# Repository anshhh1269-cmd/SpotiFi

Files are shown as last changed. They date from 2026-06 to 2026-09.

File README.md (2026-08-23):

# SpotiFi

An ESP32-powered desktop toy that interfaces with the Spotify Web API to display live track metadata, custom retro animations, and interactive player visualizations on an ILI9341 TFT display. This display is a hardware-software hybrid where physical screens meet APIs and WiFi connections.

# The Reason

Now, why did I choose this project over all amazing starter projects?
First obvi it looks more on the easier side compared to the rest of them and my main objective was to learn Fusion360 through it to master my skillset in CAD and 3D Printing. Second this display looked like something I could actually use or someone else could if they like keeping their surroundings more towards the side of a cosy vibe. 

# The Functionality

Firstly, hardware:
SpotiFi contains a TFT display, an ESP32, and five switches..each of the switches have a functionality; 

First Button: Forward
Second Button: Pause/Play
Third button: Backwards
Fourth button: 3 modes ( an inspiration from my sister); one of the modes is where the screen would show the cover image of the song/album and a character on the side which moves/vibes, others include a live oscilloscope and a character-only mode.

The ESP32 device will connect to the local Wi-Fi network of your home and use the OAuth 2.0 authentication to create a secure connection between the ESP32 and the Spotify Web API. It will send a series of background HTTP requests to the API at regular intervals in order to retrieve a real-time JSON payload containing track information such as track title, artist name, and playback state.

Then, the processed data will be transferred to the ILI9341 display controller in order to update the text and graphics on the screen. When you press any of the physical buttons, a reverse command will be sent to the Spotify server through the corresponding GPIO input.

# 3D Model Sponsorship 

# JUSTWAY Services

JUSTWAY is an online manufacturing platform that provides high-quality custom manufacturing services, including CNC machining, 3D printing, sheet metal fabrication, injection molding, PCB assembly, and 
rapid prototyping. Their platform allows engineers, makers, and students to upload CAD models, receive instant quotations, and manufacture custom parts efficiently.

# Ordering Process

**The Uploading Process**: There is an easy CAD upload for 3D Printing which gives us a 3D View right there in Justway's 
website; it consists of many options for 3D Printing along with matte paint and sanding.



**The Approval**: A good thing from Justway is that the 3D Printing job is looked at before it has been ordered for any
problems; and when it's approved, the user can then only order the job. 



**The Shipping**: Justway has multiple pages for production, delivery, and completed pages for better user interaction
and better control.

# The Unboxing

**The Packaging**: The product was safely packed under many layers when received. It was packed under a box from JustWay, secured with bubble wrap and cardboard. 





**The Product Images**: 











IMG_5625 (1)

## Dimensions and Precisions

One of the most important aspects of this project was achieving accurate dimensions, as every component inside the enclosure had to fit precisely without requiring major modifications. The USB opening was 
printed with excellent accuracy, allowing the USB connector to align perfectly with the ESP32's port. This ensured that the device could be charged and programmed easily while maintaining a clean exterior. The back cover also fit the main body precisely. The mating surfaces aligned well, creating a secure and professional fit without noticeable gaps or excessive force during assembly.

Another critical feature was the cutouts for the mechanical keyboard switches. These openings were manufactured with high dimensional accuracy, allowing the switches to fit properly and remain 
firmly seated in the enclosure. 





## End Application

Spotifi is a portable ESP32-based smart music player designed as a personal engineering project that combines embedded systems, electronics, and mechanical design. The custom enclosure securely houses
the ESP32, TFT display, battery, mechanical keyboard switches, and other electronic components, making it a functional and portable device.

## JUSTWAY Advantages

Throughout this project, JUSTWAY provided a smooth and user-friendly manufacturing experience. Uploading the CAD files and placing the order was straightforward, making the process accessible even 
for a student working on a personal engineering project.

Communication with the JUSTWAY team was also professional and responsive. Whenever I had questions regarding my order, they replied promptly and were willing to help resolve any issues.

Overall, JUSTWAY offers an excellent combination of manufacturing quality, ease of ordering, responsive customer support, and reliable precision, making it a great choice for engineers, students, 
and makers developing custom prototypes or functional products.

# The 3D Model











**Public Link: https://a360.co/4dSKmTr**

# The Wiring

Schematic_SpotiFi_2026-06-15

EasyEDA Link: https://easyeda.com/editor#project_id=699845724ab2404091f892d3d4bc927d

## 📊 Bill of Materials (BOM)

| Item | Quantity | Use | Cost (THB) + Shipping | Link |
| :--- | :---: | :--- | :---: | :--- |
| **Stranded Silicone Wires** | 4-5 meters | wire components together by solder | 630 | https://shopee.co.th/1-5-10-Meter-Number-6-30AWG-0.08mm-UL-Stranded-Silicone-Flexible-Cable-600V-200%C2%B0C-i.1096643478.27219985090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 |
| **ESP-32 30-pin** | 1 | microcontroller | 230 | https://shopee.co.th/ESP32-ESP-32-DOIT-DEVKIT-V1-Layout-Development-Board-30-Pin-i.128765755.4216421644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 |
| **LCD TFT Screen** | 2 | The screen is used to display the output from Spotify API | 300 | https://shopee.co.th/%E0%B8%82%E0%B8%AD-LCD-TFT-1.8%E0%B8%99%E0%B8%B4%E0%B9%89%E0%B8%A5-RGB-128x160px-SPI-SNP-00086-i.1272136510.26451852926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 |
| **Tactical Switches** | 5 | Switches usedto control the output executed | 63 | https://shopee.co.th/Outemu-Switch-Red-Switch-Blue-Switch-%E0%B8%9B%E0%B8%B5%E0%B9%88%E0%B8%A1%E0%B8%AA%E0%B8%A7%E0%B8%B4%E0%B8%95%E0%B8%8A%E0%B9%8C-Mechanical-Keybo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 |
| **Soldering iron** | 1 | needed to solder parts together | 179 | https://shopee.co.th/%E0%B8%8A%E0%B8%B5%E0%B8%AB%E0%B8%B5%E0%B8%A3%E0%B9%82%E0%B8%9F%E0%B8%9F%E0%B9%8A%E0%B8%B2-15-%E0%B8%8A%E0%B8%B4%E0%B8%A3-%E0%B8%A1%E0%B8%A3%E0%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 |
| **Hot glue gun sticks** | 1 pack | needed for my hot glue gun | 109 | https://shopee.co.th/50-%E0%B8%8A%E0%B8%B4%E0%B9%83%E0%B8%A3-7-%E0%B8%A1%E0%B8%B4%E0%B8%A5%E0%B8%A5%E0%B8%B4%E0%B9%80%E0%B8%A1%E0%B8%95%E0%B8%A3-100-%E0%B8%A1%E0%B8%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 |
| **Solder Wire** | 1 | needed for the soldering iron | 630 | https://shopee.co.th/63-37-Tin-Rosin-Core-20g-0.8-%E0%B8%A1%E0%B8%A1.%E0%B8%A5%E0%B8%A7%E0%B8%94%E0%B8%9A%E0%B8%B1%E0%B8%94%E0%B8%81%E0%B8%A3%E0%B8%B5%E0%B8%9E%E0%B8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 |
| **M2 Screws** | 1 | needed to screw ESP32 and TFT Screen to the 3D Printed SpotiFi | 167 | https://shopee.co.th/%E0%B8%8A%E0%B8%B5%E0%B8%94%E0%B9%80%E0%B8%AA%E0%B8%B2%E0%B8%97%E0%B8%AD%E0%B8%81%E0%B9%80%E0%B8%AB%E0%B8%A5%E0%B8%B7%E0%B8%AD%E0%B8%81-%E0%B9%8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 |

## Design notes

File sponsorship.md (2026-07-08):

# JUSTWAY Services

JUSTWAY is an online manufacturing platform that provides high-quality custom manufacturing services, including CNC machining, 3D printing, sheet metal fabrication, injection molding, PCB assembly, and 
rapid prototyping. Their platform allows engineers, makers, and students to upload CAD models, receive instant quotations, and manufacture custom parts efficiently.

# SpotiFi Background

Spotifi is a portable Spotify-inspired music player that I designed and built from scratch as a personal engineering project. The device integrates an ESP32, TFT display, custom electronics, and a 3D-printed
enclosure. Since every internal component had to fit precisely, I designed the enclosure entirely in CAD and required accurate custom 3D printing. Moreover, it consists of five switches; those are for volume/back/forward,
the fifth switch is for three modes which are character display, song display and oscilloscope display.

# Ordering Process

**The Uploading Process**: There is an easy CAD upload for 3D Printing which gives us a 3D View right there in Justway's 
website; it consists of many options for 3D Printing along with matte paint and sanding.



**The Approval**: A good thing from Justway is that the 3D Printing job is looked at before it has been ordered for any
problems; and when it's approved, the user can then only order the job. 



**The Shipping**: Justway has multiple pages for production, delivery, and completed pages for better user interaction
and better control.

# The Unboxing

**The Packaging**: The product was safely packed under many layers when received. It was packed under a box from JustWay, secured with bubble wrap and cardboard. 





**The Product Images**: 











IMG_5625 (1)

## Dimensions and Precisions

One of the most important aspects of this project was achieving accurate dimensions, as every component inside the enclosure had to fit precisely without requiring major modifications. The USB opening was 
printed with excellent accuracy, allowing the USB connector to align perfectly with the ESP32's port. This ensured that the device could be charged and programmed easily while maintaining a clean exterior. The back cover also fit the main body precisely. The mating surfaces aligned well, creating a secure and professional fit without noticeable gaps or excessive force during assembly.

Another critical feature was the cutouts for the mechanical keyboard switches. These openings were manufactured with high dimensional accuracy, allowing the switches to fit properly and remain 
firmly seated in the enclosure. 





## End Application

Spotifi is a portable ESP32-based smart music player designed as a personal engineering project that combines embedded systems, electronics, and mechanical design. The custom enclosure securely houses
the ESP32, TFT display, battery, mechanical keyboard switches, and other electronic components, making it a functional and portable device.

## JUSTWAY Advantages

Throughout this project, JUSTWAY provided a smooth and user-friendly manufacturing experience. Uploading the CAD files and placing the order was straightforward, making the process accessible even 
for a student working on a personal engineering project.

Communication with the JUSTWAY team was also professional and responsive. Whenever I had questions regarding my order, they replied promptly and were willing to help resolve any issues.

Overall, JUSTWAY offers an excellent combination of manufacturing quality, ease of ordering, responsive customer support, and reliable precision, making it a great choice for engineers, students, 
and makers developing custom prototypes or functional products.

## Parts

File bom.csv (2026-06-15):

Item | Quantity | Use | Cost(thb)+shipping | Link
Stranded Silicone Wires | 4-5 meters | wire components together by solder | 630 | https://shopee.co.th/1-5-10-Meter-Number-6-30AWG-0.08mm-UL-Stranded-Silicone-Flexible-Cable-600V-200%C2%B0C-i.1096643478.27219985090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
ESP-32 30-pin | 1 | microcontroller | 230 | https://shopee.co.th/ESP32-ESP-32-DOIT-DEVKIT-V1-Layout-Development-Board-30-Pin-i.128765755.4216421644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
LCD TFT Screen | 2 | The screen is used to display the output from Spotify API | 300 | https://shopee.co.th/%E0%B8%88%E0%B8%AD-LCD-TFT-1.8%E0%B8%99%E0%B8%B4%E0%B9%89%E0%B8%A7-RGB-128x160px-SPI-SNP-00086-i.1272136510.26451852926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
Tactical Switches | 5 | Switches usedto control the output executed | 63 | https://shopee.co.th/Outemu-Switch-Red-Switch-Blue-Switch-%E0%B8%9B%E0%B8%B8%E0%B9%88%E0%B8%A1%E0%B8%AA%E0%B8%A7%E0%B8%B4%E0%B8%95%E0%B8%8A%E0%B9%8C-Mechanica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
Soldering iron | 1 | needed to solder parts together | 179 | https://shopee.co.th/%E0%B8%8A%E0%B8%B8%E0%B8%94%E0%B8%AB%E0%B8%B1%E0%B8%A7%E0%B9%81%E0%B8%A3%E0%B9%89%E0%B8%87%E0%B9%84%E0%B8%9F%E0%B8%9F%E0%B9%89%E0%B8%B2-1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
Hot glue gun sticks | 1 pack | needed for my hot glue gun | 109 | https://shopee.co.th/50-%E0%B8%8A%E0%B8%B4%E0%B9%89%E0%B8%99-7-%E0%B8%A1%E0%B8%B4%E0%B8%A5%E0%B8%A5%E0%B8%B4%E0%B9%80%E0%B8%A1%E0%B8%95%E0%B8%A3-100-%E0%B8%A1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
Solder Wire | 1 | needed for the soldering iron | 630 | https://shopee.co.th/63-37-Tin-Rosin-Core-20g-0.8-%E0%B8%A1%E0%B8%A1.%E0%B8%A5%E0%B8%A7%E0%B8%94%E0%B8%9A%E0%B8%B1%E0%B8%94%E0%B8%81%E0%B8%A3%E0%B8%B5%E0%B8%9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
M2 Screws | 1 | needed to screw ESP32 and TFT Screen to the 3D Printed SpotiFi | 167 | https://shopee.co.th/%E0%B8%8A%E0%B8%B8%E0%B8%94%E0%B9%80%E0%B8%AA%E0%B8%B2%E0%B8%97%E0%B8%AD%E0%B8%87%E0%B9%80%E0%B8%AB%E0%B8%A5%E0%B8%B7%E0%B8%AD%E0%B8%87-%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

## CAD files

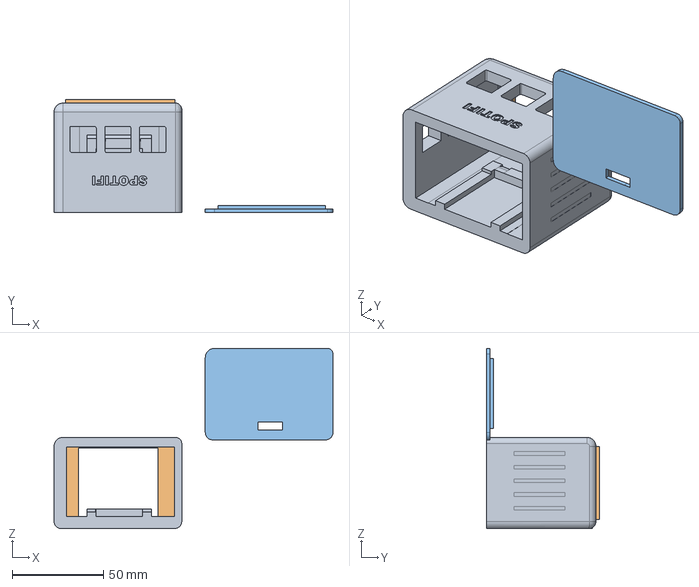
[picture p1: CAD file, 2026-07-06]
3D Model/SpotiFi (5).stp
152.8 x 62.0 x 98.7 mm

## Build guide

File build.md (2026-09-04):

# 2026-08-24: time for the three switchess

**Total time spent: 1.2 hours**

aight so now the clay thing from last time was def not working cause it was kinda conducting but it was slipping out whenever put in a cramped position so i thought and thought...andd 
HOTT GLUE came in my mind why not hot glue the female header pins directly to the base of the switches it wont move that easily even when positioned a lot or 
its position is changed many times

so i hot glued three switches meaning six header wires did take some time cause hot glue is kinda messy but then it was stuck perfectly..moving onto the problem of connecting the three 
gnd wires to one GND pin on the esp32..now solder wasnt working out for me so i basically had to get **creative** again and again..so i had an idea of those three gnd wires im gonna 
scrape the end and expose the copper

then the expose copper can be layered onto the pin of the esp32 but one thing was it could come off again..and then on my table those circle stickers were kept which had glue on the other side;
so i took out one cut it into a small piece and then put the glue tape on both the sides of the gnd pin of the esp and then just stick it..and then i used those tightening wires and then 
it kinda worked dont knowif it will come out but temporary fix :)

thats it for tdy :)

WhatsApp Image 2026-09-04 at 23 38 32

WhatsApp Image 2026-09-04 at 23 38 32 (1)

# 2026-08-22: the wiring

**Total time spent: 0.67 hours**

okay so i connected the wires from the screen header pins to the esp32 along with one switch with clay idk how to do it man im confused let’s see
thats it for tdy :)

# 2026-08-21: got the pcb

**Total time spent: 1.3 hours**

okay i got the pcb and header pins; started soldering the header pins on the pcb..but idk why when i connected th wires the screen aint turning on
idk gotta see wat happened..anw thats it for tdy :); **lapse link: https://lapse.hackclub.com/timelapse/vXb8___Yu2VA**



# 2026-08-13: designed PCB

**Total time spent: 1.2 hours**

so yea i tried everything to connect the wires with soldering, black tape and nothing is sticking honestly and idk why..
so ill be ordering a pcb from jlcpcb and i have designed it..dont have a lapse for it cause forgot but took me a little more than an hour..i added a 10 header pin and a eight header pin for the screen and the switches so its easy to connect and stuff so lets see if this will work too..
thats it for tdy :)





# 2026-08-08: doing the switches

**Total time spent: 1.5 hours**

so tdy was trial and error; i tried soldering the wires onto the siwtches but it aint sticking man idk why i think i gotta learn still
however im trying to do it with tape and honestly no progress yet but this lapse was me trying it :(

**lapse link: https://lapse.hackclub.com/timelapse/6K3eVTo8P4Ux**



# 2026-08-05: assembly time

**Total time spent: 1.25 hours**

so im using the female-to-female wires now; first i started with looking on how the screen would attach to the 3D printed body; used black tape and did again and again cause my 3d print wasnt that perfect :(
and then after that started to use the female-to-female wires however the solder lump was still on the pins so it wasnt fitting; rmeoved the solder iron again and heaed it up to remove those tiny lumps;
after that i connected everything carefully but however there is a slight problem; the usb cable which connects to the esp32 port is to big to fit through my back case hole; idk what to do will check and research :(

**lapse link: https://lapse.hackclub.com/timelapse/SK1I42jsH6JG**



# 2026-08-05: removing the soldered wiress

**Total time spent: 0.5 hours**

okay so picking up where i left on soldering; the soldering wasnt working well on the pins so im gonna be using 10cm F-F wires..

**lapse link: https://lapse.hackclub.com/timelapse/jAO-Ja1L0aNU**



# 2026-08-02: soldering part one

**Total time spent: 2 hours**

soo end result i hate soldering now and i have crashed out..i have offically ordered smaller female-female wires cause this soldering thing will take time to master :(
kinda bad technique the wires did stick first but came out when i tried some other pinn near it..will learn but not now :(

**lapse link: https://lapse.hackclub.com/timelapse/k3ah_FwGRwMV**



# 2026-07-28: finished the initial wiring

**Total time spent: 0.67 hours**

so i got the female=to-female connecting wires and started to put them into use..first thing was to connect the screen to the esp32 which seemed hard at first cause i havent done any hardware yet..but this seemed so easy
i didnt even have to use chat for this just used the knowledge i gained before while doing the design and just translated into real life..
added a time lapse video too..seems very bad ngl but yea it is what it is
thats it for rn..and also i added one switch to it..cant add five switches using the wires due to GND prob..so im just gonna use this switch and try out the coding like character dancing or spotify api connecting.

**lapse link: https://lapse.hackclub.com/timelapse/BUhdfQgGlOS-**



# 2026-07-27: STARTED the build :)

**Total time spent: 1.2 hours**

okay so my first build..pretty excited
so the first thing was to find the cheapest switches, esp32, and the tft screen which was quite easy..also started to find soldering kit along with solder wire, and a data USB cable cause i dont have one which works..
the things came and i have just started out to test the esp32 nothing else no code yet; and a thing came to my mind which was supposed to come way before; ill use the female-to-female connectors instead of solder just for testing so i dont have to solder and rmeove solder again and again...already ordered those
so this devlog covered the ordering time, along with the esp32 and i also got the 3d print through a sponsorship from justway!







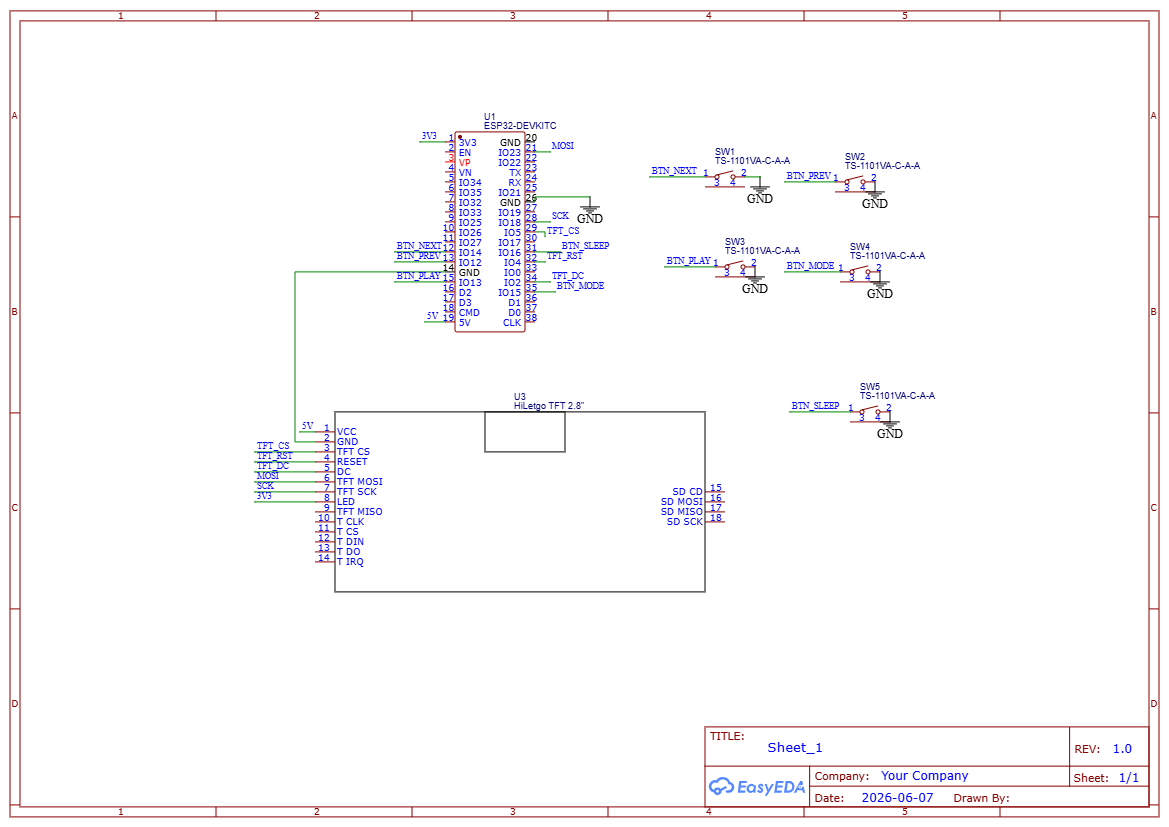
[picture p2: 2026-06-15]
Wiring/Schemantic.png

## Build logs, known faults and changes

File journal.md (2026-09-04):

# 2026-06-15: wiring and keyboard buttons

**Total time spent: 2.50 hours**

so basiclly my proj got returned today..main thing was the wiring was so messy and not exactly an easy readable file..so what I did was use net label in easyEDA which i've never heard off...its basically like u can write the pin u want to connect to each end of the wire without making these long green ones

however i did crashout kinda today..so i did one wire like this and i had to check if it was rlly connected..AI told me to click one of the label and the other label should highlight automatically, however it didnt...and tried again and still no outcome

asked for other option where i ahd to check in the nets tab in easyEDA and when i cliked "5V" both of them had highlighted so got a bit excited

did for all and it kinda looks clean and then moving onto the keyboard..so basically i had got the keyboard buttons from GRABCAD but i forgot to even try it in the holes made..did it today and got it on perfectly; took some time as i had to figure out the correct angle and everything :(

moving onto finding the 3D quote in 3D Legion by hackclub :)





# 2026-06-07: code completed

**Total time spent: 1.1 hours**

yea so made the code for the esp32...first listed out the libraries needed then explained and executed each and every possibilities for each mode...made it so that the eso32 uses my home wifi by inputting the ssid and its password

so hwo this works is that when the ESP32 gets fired up it connects to my WiFi and then connects through the Spotify's API provided by me through the user code and secret code, then it would request the API to send cover album, name, title and sound track to track the oscilloscope..

the character dancing on one of the modes would be like a pre-decided one which would be in the code made by hexadecimal and binary codes.

couldnt be seen in hacaktime due to some error i think and also i tried time lapse and the whole file just got deleted

i took like 1.5hrs but ill write it as one hr :)



# 2026-06-07: recheck everything

**Total time spent: 4.1 hours**

so i had to check everything today...gguess what?

the TFT screen which i used is way bigger in real life and now the screen might not even make it..however i tried not to waste time with it but i did go through the timeline to recheck again

found everything online today and made the bom.csv too (took 30 mins) now working on the code and also looked up a 3D Printer vendor today and made a quote so yeaa...

AND also worked on the wiring in easyeda which took time but i think i did it well...i might do like a simulation of these all parts and recheck everything

ANDDD remember the shadowing effect on the tft screen on the back side..so today i went back to the timeline and made the initial rectangle smaller and finally i cud see the screw mounts on the back side and that helped a lott...but the thing is since the real size cud be bigger or smaller than this i thought to add screws on the mounts but that didn't work out since the circles weren't allowing me to sketch on the components idk why..

so then i asked people and AI for some advice and they said that maybe using glu tack would be a better resort and i thought that would be good too, instead of drilling more holes and cylinders on the 3D structure :)

thats it :)





# 2026-06-05: made the cover more proper

**Total time spent: 2.0 hours**

NOWW THE BAD THING HAPPENED!

now before in one of the devlogs i made the back cover but i forgot to actually check it by putting/moving it on the back side of the case

well i did it today and guess what? the usb port wasnt in the hole like only 50% of it was in there...so again i had to take some dimensions and make the hole more bigger on the case, and then after some trial and error, it had finally fit and i had a sigh of relief honestly.

and honestly i way i could have gone was to just make the hole more bigger but then that would defeat its purpose to just show the usb port and dust could also form so i took all dimensions again and then did the whole thing again..





# 2026-06-04: added some kinda cool things

**Total time spent: 2.67 hours**

so first after some time off from my exams i started to work on this project...

someone gave me an advice and told me to add like a continuous LED screen which showed the song playing on each side...however later after one hr of tryin i found that i couldn't do it cause the filet and some other locked things weren't letting me change the dimensions :(

and then just to make timepass i added some cool things like SPOTFI on top and added some grip grooves on each side idk just like that and also fixed sum things by going back in the timeline

now these grooves are obvi for cool deisgns and also to decrease and shed some weight out of it to make it more portable.





# 2026-05-25: big day today

**Total time spent: 4.3 hours**

sooo basically i got the case working after sooo long...first i was making the case on the back side but it wasn't workin so i just got each and every dimensions and made the case seperately and its fittinggg :)

so firstly, didnt know how to make a back case..had some help..soo first i did like took all the dimensions of the outer rectangle, inner and inner with a gap of 2mm and more important the usb hole so that the port can just slide in and be open to any connections to the ESP 32. however, idk why when i did that the case wasn't coming out and i couldn't obvi make a 3D print with both of em being together;

so then i had an idea to just make it in the universe take all the dimensions again exactly like how far is this line from the outer and everything which took some time to memorize and execute but it did happen eventually;

also matched the 5mm filets and i think it would be good





# 2026-05-24: added the ESP32...and made it's case

**Total time spent: 3.5 hours**

soo basically i have figured out on how to attach the ESP32 to the bottom of the case abd it actually worked..kinda

and also made a case for it and also added two rectangles on top of it to secure the ESP..

now see in this pic you guys cud see the shadow thingy i was talking for the screen and how its corners arent even visible i think its just submerged in the corners gotta make it small by going through the timeline..also these rectangles on the side and on the top would prevent left-right motion and for the upward and downward i thought to create some other rectangle but i think making a back cover would solve all problems and would also make this project more smoother and like it would have a closing gap.

next im gonna make a back cover and then on to the keyboard stuff...



# 2026-05-23: added ths screen and working on ESP32

**Total time spent: 3.5 hours**

so basically i added the screen now and it actually maybe looks like what im hoping for :)...so basically the screen is coming out, which it should do but also when im trying to use the "m" function in fusion by selecting points of ESP and that inward part it just doesnt seem to be working..idk will look into it :(

more things which i did obvi first extruded from the first part to make like a box and an extra thing was to filet the edges so it kinda looks cool..did it like 5mm hopefully thats enough;

moreover, idk why but the red part of the screen behind it is coming as a shadow like its having those color effects idk why may look to fix it a bit later i think.

adding the esp32 and hiding its pins so its easy to move was another thing done in this part

but that's it for tdy; next thing would be placing the esp32 and creating its borders so it doesn't move left and right.



# 2026-05-21: the start of a hardware journey :)

**Total time spent: 2 hours**

soo basically i have got the parts needed for this project, the screen, keyboard and the ESP32 from GRABCAD community..and i have started to make the base

thats it :) annddd im using fusion for the first time :)

so for this part what i have done is like create an outlier rectangle for the screen and then extrude so that the screen is the only one shown and not the red parts. bad thing was i took soe extra time to figure out everything like extrude/dimensions and everything :(



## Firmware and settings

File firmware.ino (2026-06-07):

#include <Arduino.h>
#include <ArduinoJson.h>
#include <Adafruit_GFX.h>
#include <Adafruit_ST7735.h>
#include <WiFi.h>
#include <HTTPClient.h>
#include <WiFiClientSecure.h>
#include <JPEGDecoder.h>
#include <SpotifyEsp32.h>
#include <SPI.h>

// ============================================================================
// 1. HARDWARE PIN CONFIGURATIONS
// ============================================================================
#define BTN_NEXT  14  
#define BTN_PREV  12  
#define BTN_PLAY  13  
#define BTN_MODE  15  
#define BTN_SLEEP 16  

#define TFT_CS    5
#define TFT_RST   4
#define TFT_DC    2
#define TFT_SCLK  18
#define TFT_MOSI  23


const char* SSID          = "YOUR WIFI SSID";
const char* PASSWORD      = "YOUR WIFI PASSWORD";
const char* CLIENT_ID     = "YOUR_SPOTIFY_CLIENT_ID";
const char* CLIENT_SECRET = "YOUR_SPOTIFY_CLIENT_SECRET";


const uint16_t charFrame1[] PROGMEM = {
    0x0000, 0x0000, 0x07E0, 0x07E0, 0x07E0, 0x07E0, 0x0000, 0x0000,
    0x0000, 0x07E0, 0xFFFF, 0x07E0, 0x07E0, 0xFFFF, 0x07E0, 0x0000,
    0x07E0, 0x07E0, 0x07E0, 0x07E0, 0x07E0, 0x07E0, 0x07E0, 0x07E0,
    0x07E0, 0x0000, 0x07E0, 0x07E0, 0x07E0, 0x07E0, 0x0000, 0x07E0,
    0x07E0, 0x07E0, 0x07E0, 0x07E0, 0x07E0, 0x07E0, 0x07E0, 0x07E0,
    0x0000, 0x07E0, 0x07E0, 0x07E0, 0x07E0, 0x07E0, 0x07E0, 0x0000,
    0x0000, 0x07E0, 0x0000, 0x0000, 0x0000, 0x0000, 0x07E0, 0x0000,
    0x0000, 0xF800, 0x0000, 0x0000, 0x0000, 0x0000, 0xF800, 0x0000
};

const uint16_t charFrame2[] PROGMEM = {
    0x0000, 0x0000, 0x07E0, 0x07E0, 0x07E0, 0x07E0, 0x0000, 0x0000,
    0x0000, 0x07E0, 0xFFFF, 0x07E0, 0x07E0, 0xFFFF, 0x07E0, 0x0000,
    0x07E0, 0x07E0, 0x07E0, 0x07E0, 0x07E0, 0x07E0, 0x07E0, 0x07E0,
    0x07E0, 0x07E0, 0x0000, 0x07E0, 0x07E0, 0x0000, 0x07E0, 0x07E0,
    0x07E0, 0x07E0, 0x07E0, 0x07E0, 0x07E0, 0x07E0, 0x07E0, 0x07E0,
    0x0000, 0x0000, 0x07E0, 0x07E0, 0x07E0, 0x07E0, 0x0000, 0x0000,
    0x0000, 0x0000, 0x07E0, 0x0000, 0x0000, 0x07E0, 0x0000, 0x0000,
    0x0000, 0x0000, 0xF800, 0x0000, 0x0000, 0xF800, 0x0000, 0x0000
};


enum DisplayMode { BOOT_TEXT, ALBUM_ART_CHAR, ONLY_CHAR, OSCILLOSCOPE };
DisplayMode currentMode = BOOT_TEXT; 

bool screenSleep = false;
String lastTrackname = "";
String lastArtist = "";
String lastAlbumUrl = "";
unsigned long lastAnimationTime = 0;
unsigned long lastSpotifyUpdate = 0;
int animationFrame = 0;
float wavePhase = 0;

float realLoudness = -10.0; 
float realBPM = 120.0;       

Spotify sp(CLIENT_ID, CLIENT_SECRET);
Adafruit_ST7735 tft = Adafruit_ST7735(TFT_CS, TFT_DC, TFT_MOSI, TFT_SCLK, TFT_RST);

// Forward Declarations
int checkMultiClicks(int pin);
void drawSpotifyAlbumArt(String url);
void renderJPEG(int xpos, int ypos);
void drawTrackText(String track, String artist);
void fetchLiveAudioFeatures(String trackId);

void setup() {
    Serial.begin(115200);
    
    pinMode(BTN_NEXT, INPUT_PULLUP);
    pinMode(BTN_PREV, INPUT_PULLUP);
    pinMode(BTN_PLAY, INPUT_PULLUP);
    pinMode(BTN_MODE, INPUT_PULLUP);
    pinMode(BTN_SLEEP, INPUT_PULLUP);

    tft.initR(INITR_BLACKTAB);
    tft.setRotation(1); 
    tft.fillScreen(ST77XX_BLACK);
    
    tft.setCursor(10, 20);
    tft.setTextColor(ST77XX_WHITE);
    tft.setTextSize(1);
    tft.print("Booting Connection...");

    WiFi.begin(SSID, PASSWORD);
    while (WiFi.status() != WL_CONNECTED) {
        delay(500);
        Serial.print(".");
    }
    
    tft.fillScreen(ST77XX_BLACK);
    tft.setCursor(10, 20);
    tft.print("Syncing Spotify API...");

    sp.begin();
    while (!sp.is_auth()) {
        sp.handle_client();
        delay(10);
    }
    tft.fillScreen(ST77XX_BLACK);
    currentMode = ALBUM_ART_CHAR; 
}

void loop() {
    sp.handle_client();

    
    if (digitalRead(BTN_NEXT) == LOW) { sp.skip_to_next(); delay(300); }
    if (digitalRead(BTN_PREV) == LOW) { sp.skip_to_previous(); delay(300); }
    if (digitalRead(BTN_PLAY) == LOW) { sp.start_a_users_playback(); delay(300); }
    if (digitalRead(BTN_SLEEP) == LOW) {
        screenSleep = !screenSleep;
        if (screenSleep) tft.fillScreen(ST77XX_BLACK);
        else { lastAlbumUrl = ""; lastTrackname = ""; }
        delay(350);
    }

    if (screenSleep) return; 

    int clicks = checkMultiClicks(BTN_MODE);
    if (clicks == 1) { currentMode = ALBUM_ART_CHAR; tft.fillScreen(ST77XX_BLACK); lastAlbumUrl = ""; lastTrackname = ""; }
    else if (clicks == 2) { currentMode = ONLY_CHAR; tft.fillScreen(ST77XX_BLACK); }
    else if (clicks == 3) { currentMode = OSCILLOSCOPE; tft.fillScreen(ST77XX_BLACK); }

   
    static String currentTrack = "";
    static String currentArtist = "";
    static String currentAlbumUrl = "";
    static String lastTrackId = "";
    static bool isPlaying = false;

    if (millis() - lastSpotifyUpdate > 2000) {
        lastSpotifyUpdate = millis();
        currentTrack    = sp.current_track_name();
        currentArtist   = sp.current_artist_names();
        currentAlbumUrl = sp.get_current_album_image_url(2); 
        isPlaying       = sp.is_playing();
        
        String currentTrackId = sp.current_track_id(); 
        
        if (currentTrackId != lastTrackId && !currentTrackId.isEmpty()) {
            fetchLiveAudioFeatures(currentTrackId);
            lastTrackId = currentTrackId;
        }
    }

    
    switch (currentMode) {
        
        case ALBUM_ART_CHAR:
            if (currentTrack != lastTrackname) {
                drawTrackText(currentTrack, currentArtist);
                lastTrackname = currentTrack;
                lastArtist = currentArtist;
            }
            if (currentAlbumUrl != lastAlbumUrl && !currentAlbumUrl.isEmpty()) {
                tft.fillRect(10, 32, 64, 64, ST77XX_BLACK); 
                drawSpotifyAlbumArt(currentAlbumUrl); 
                lastAlbumUrl = currentAlbumUrl;
            }
            if (millis() - lastAnimationTime > 400) {
                lastAnimationTime = millis();
                tft.fillRect(120, 56, 16, 16, ST77XX_BLACK); 
                if (isPlaying) animationFrame = (animationFrame == 0) ? 1 : 0;
                
                int startX = 120;
                int startY = 56;
                int scale = 2;
                const uint16_t* currentFrame = (animationFrame == 0) ? charFrame1 : charFrame2;
                for (int row = 0; row < 8; row++) {
                    for (int col = 0; col < 8; col++) {
                        uint16_t color = pgm_read_word(&(currentFrame[row * 8 + col]));
                        if(color != 0x0000) { 
                            tft.fillRect(startX + (col * scale), startY + (row * scale), scale, scale, color);
                        }
                    }
                }
            }
            break;

        case ONLY_CHAR:
            if (millis() - lastAnimationTime > 200) {
                lastAnimationTime = millis();
                tft.fillRect(48, 32, 64, 64, ST77XX_BLACK); 
                if (isPlaying) animationFrame = (animationFrame == 0) ? 1 : 0;
                
                int startX = 48;
                int startY = 32;
                int scale = 8;
                const uint16_t* currentFrame = (animationFrame == 0) ? charFrame1 : charFrame2;
                for (int row = 0; row < 8; row++) {
                    for (int col = 0; col < 8; col++) {
                        uint16_t color = pgm_read_word(&(currentFrame[row * 8 + col]));
                        if(color != 0x0000) {
                            tft.fillRect(startX + (col * scale), startY + (row * scale), scale, scale, color);
                        }
                    }
                }
            }
            break;

        case OSCILLOSCOPE:
            tft.fillRect(0, 40, 160, 50, ST77XX_BLACK); 
            if (isPlaying) {
                // Map real decibel loudness (typically ranges around -20dB to -3dB) to visual amplitude bounds
                int amplitude = map(constrain((int)realLoudness, -25, -2), -25, -2, 4, 23);
                
                float speedFactor = (realBPM / 120.0) * 5.0;
                wavePhase += speedFactor; 

                for (int x = 0; x < 160; x++) {
                    int y = 64 + (amplitude * sin((x + wavePhase) * 0.09));
                    tft.drawPixel(x, y, ST77XX_CYAN); 
                }
            } else {
                tft.drawFastHLine(0, 64, 160, ST77XX_RED); 
            }
            delay(15); 
            break;
            
        default:
            break;
    }
}


void fetchLiveAudioFeatures(String trackId) {
    WiFiClientSecure client;
    client.setInsecure(); 
    HTTPClient http;
    
    String url = "https://api.spotify.com/v1/audio-features/" + trackId;
    
    if (http.begin(client, url)) {
        // FIXED: Using wrapper's core token getter structure variables
        String headerAuth = "Bearer " + String(sp.get_access_token()); 
        http.addHeader("Authorization", headerAuth);
        
        int httpCode = http.GET();
        if (httpCode == HTTP_CODE_OK) {
            String response = http.getString();
            JsonDocument doc;
            deserializeJson(doc, response);
            
            if (doc.containsKey("loudness")) realLoudness = doc["loudness"].as<float>();
            if (doc.containsKey("tempo")) realBPM = doc["tempo"].as<float>();
            
            Serial.print("REAL TRACK SYNC -> Loudness: "); Serial.print(realLoudness);
            Serial.print(" dB | Tempo: "); Serial.print(realBPM); Serial.println(" BPM");
        }
        http.end();
    }
}



void drawTrackText(String track, String artist) {
    tft.fillRect(0, 0, 160, 28, ST77XX_BLACK);
    tft.setTextWrap(false);
    tft.setTextColor(ST77XX_GREEN); 
    tft.setTextSize(1);
    tft.setCursor(10, 4);
    tft.print(track.substring(0, 24).c_str()); 

    tft.setCursor(10, 16);
    tft.setTextColor(ST77XX_WHITE);
    tft.print(artist.substring(0, 26).c_str());
}

void drawSpotifyAlbumArt(String url) {
    WiFiClientSecure client;
    client.setInsecure(); 
    HTTPClient http;
    if (http.begin(client, url)) {
        int httpCode = http.GET();
        if (httpCode == HTTP_CODE_OK) {
            int totalBytes = http.getSize();
            
            // FIXED: Allocate an explicit heap array storage buffer to decode arrays safely without stream pointer casts
            uint8_t* artBuffer = (uint8_t*)malloc(totalBytes);
            if (artBuffer != NULL) {
                WiFiClient* stream = http.getStreamPtr();
                stream->readBytes(artBuffer, totalBytes);
                
                // Decode using the verified array parser matching your JPEGDecoder footprint
                if (JpegDec.decodeArray(artBuffer, totalBytes)) {
                    renderJPEG(10, 32); 
                }
                free(artBuffer); 
            }
        }
        http.end();
    }
}

void renderJPEG(int xpos, int ypos) {
    uint16_t *pImg;
    uint16_t mcu_w = JpegDec.MCUWidth;
    uint16_t mcu_h = JpegDec.MCUHeight;
    while (JpegDec.read()) {
        pImg = JpegDec.pImage;
        int mcu_x = JpegDec.MCUx * mcu_w + xpos;
        int mcu_y = JpegDec.MCUy * mcu_h + ypos;
        if ((mcu_x + mcu_w <= tft.width()) && (mcu_y + mcu_h <= tft.height())) {
            tft.drawRGBBitmap(mcu_x, mcu_y, pImg, mcu_w, mcu_h);
        }
    }
}

int checkMultiClicks(int pin) {
    static bool lastButtonState = HIGH;
    static unsigned long firstClickTime = 0;
    static int clickCounter = 0;
    bool currentButtonState = digitalRead(pin);
    int resultClicks = 0;

    if (currentButtonState == LOW && lastButtonState == HIGH) {
        delay(20); 
        if (clickCounter == 0) firstClickTime = millis();
        clickCounter++;
    }
    lastButtonState = currentButtonState;

    if (clickCounter > 0 && (millis() - firstClickTime > 400)) {
        resultClicks = clickCounter;
        clickCounter = 0; 
        if (resultClicks > 3) resultClicks = 3; 
    }
    return resultClicks;
}

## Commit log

2026-06-15 Rename SpotiFi 3D Model to SpotiFi 3D Model.stp
    [SpotiFi 3D Model.stp]
2026-06-15 Rename SpotiFi (1).stp to 3D Model/SpotiFi.stp
    [SpotiFi.stp]
